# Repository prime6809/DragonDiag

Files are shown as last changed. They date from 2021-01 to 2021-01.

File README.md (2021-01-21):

# DragonDiag
Diagnotic card for the Dragon 32/64 and Tandy CoCo 1,2,3.

Included is the Hardware design files created in Eagle, these should be 
compatible with any version of Eagale 6.x or later. Recent versions of 
KiCad should also be able to successfully import them.
Folder: hardware

The Verilog source for the onboard XC95144XL CPLD. This can be built with
Xilinx WebPack 14.7.
Folder: cpld

The 6809 source to the diagnostic ROM generally programed into the first 
8K of the onboard flash rom. To assemble this you will need lwasm available
from http://www.lwtools.ca/ You will also need a nnix compatible make utility
I generally use cygwin, but it should be builable under Linux / Macos or 
any unix like environment with the correct tools.
Folder: src

The stl files for a case for both the diag board and the LCD display are
also provided along the the FreeCAD source files.
Folder: case

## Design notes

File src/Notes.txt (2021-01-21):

Notes for the Dragon/CoCo Diag cart.

V1.30 2020-05-27, Phill Harvey-Smith.

The Diag cart will perform the following tests on a Dragon 32, Dragon 64, Tandy
CoCo 1 or Tandy CoCo 2. It has as yet not been tested with a CoCo 3. 

The following tests will be performed in order :
Tests marked ** are *NOT* carried out on the CoCo3, as they are not relevant to
that machine 

1) 	Onboard SRAM test (SRAM on the card).  A failure at this point will
	prevent further testing, this will be indicated by the 8 LEDS on the
	bargraph coming on....this should never happen :)
	
2) 	PIAs and SAM initialized acording to DIP switches and motherboard jumpers.
	On the CoCo3 the GIME registers are also setup as needed.
	
3) 	Video ram at $0400-$0600 tested. If working output will be to screen as 
	well as LCD.
	The configured machine and detected RAM chip type will be displayed.

4) 	A quick memory test of the bottom 2 memory areas will be done. The size
	of the memory areas will be determined from the memory type selection
	jumpers on the Dragon or CoCo motherboard. They are :-

	CoCo with 4K RAMS		Dragon/CoCo with 16K or 64K RAMS
	block 0	$0000-$0FFF		$0000-$3FFF
	block 1 $1000-$1FFF  	$4000-$7FFF

	If A RAM failure occurs, then the test is eneded, and the address that 
	the failure occured at plus the data byte read and written are displayed.
	Further testing then halts until the 'next' button is pressed, this will
	end further testing of this bank.
	Pressing S3 allows the test to continue at the location following the
	location with error.

5) 	A RAM address line test, carried out in two halves testing first the 
	bottom 8 address lines then the top 8. This should help to detect address
	line faults between the CPU and SAM/GIME.

6) 	The two onboard ROM blocks $8000-$9FFF and $A000-$BFFF are checksumed. The
	checksums are displayed on the LCD and screen. In addition if the ROM has a
	recognized checksum, then it's idenetity is also displayed on the VDG screen.
	See ROM checksum table further down for expected values.
	
7) 	The PIA registers for the standard 2 PIAs at $FF00 and $FF20 are then dumped.
	Their expected contents in the Control and DDR registers of each port are checked,
	and the status displayed OK/NO on the VDG or Y/N on the LCD.
	
8) 	The number of spurious NMI and FIRQ interrupts are displayed. (there should 
	be none).

9) 	The above interrupts are then tested by being triggered via the onboard CPLD,
	and the results displayed.

	The IRQ interrupt is also enabled, from the VDG, if working LED X1 will begin 
	flashing approximately once per second.
   
10) The CART / CTS and P2 / SCS signals will then be tested by triggering them 
	using the CPLD, and the status displayed, either pass if they trigger as 
	expected, fail if they do not, or "stuck low" if they are low when not 
	being triggered.
	
11) ** If the DIP switch is set for long tests, then a more exhaustive long memory test
	is performed. As with the quick test it will stop on failure and wait for the 
	'next' button to be pressed.
	
12) **	If the appropreate DIP switches are set the Dragon 64 tests are done. These 
    	are:
		a) Checksumming the ROM that is copied into upper RAM when booted into 
		   RAM mode. 	
		b) Dumping the ACIA registers.

13) ** 	If the machine is detected as having 64K DRAMS, then the upper half of the 
	64K of RAM is tested. If the long test DIP is set, then the long test is ran 
	otherwise the short test.
	
14) **	The Dragon Plus addon is probed for, if found it's RAM is also tested.	

15) 	If the machine is a CoCo 3, the following additional tests are done :

		a) The additional ROMS at $C000-$FDFF are read and checksummed, 
		   and results displayed on screen / LCD.
	
		b) The ammount of RAM 128K or 512K is probed for, sequentially
		   paged in (8K at a time) and tested, whilst testing it's block
		   number is displayed plus the normal PASSED or error report.
		   
16) 	At this point all tests are complete, a message will be displayed and the
    	user has the option of pressing 'next' to enter toggle mode. 
	
Toggle mode.

As an aid to fault tracing, toggle mode is entered once all tests are complete
this mode will repeatedly read the addresses of different parts of the system so
that the correct operaion of the chip select lines can be verified.

The things toggled are :

device		Base	74LS138 pin	In addition
RAM read 	$0000	Y0 pin 15	/RAS on bank 0 of RAMS
RAM read 	$1000	Y0 pin 15	/RAS on bank 1 of RAMS (4K) **	
RAM read 	$4000	Y0 pin 15	/RAS on bank 1 of RAMS (16K) **
ROM0 		$8000	Y1 pin 14	
ROM1		$A000	Y2 pin 13
ROM2 (cart)	$C000	Y3 pin 12
PIA0		$FF00	Y4 pin 11
PIA1		$FF20	Y5 pin 10
I/O 2 (cart)	$FF40	Y6 pin 9
RAM write 	$0000	Y7 pin 7	/RAS and /WE on bank 0 of RAMS
RAM write	$1000	Y7 pin 7	/RAS and /WE on bank 1 of RAMS (4K) **	
RAM write	$4000	Y7 pin 7	/RAS and /WE on bank 1 of RAMS (16K) **

** On machines with 64K RAMs there is only one RAS signal so RAS0 will toggle 
not RAS1.
 	
Whilst in toggle mode the following keys are available

	Next will exit the toggle mode and restart the diag cart.
	S3 will move to the next toggle in the list, looping at the end.
	S4 will move to the previous toggle in the list, looping at the beginning.

User interface buttons :
There are currently 4 buttons on the card, of which 3 are currently used

	Label			Purpose
	S1 / Next		Moves to the next test, after an error occurs.
	S2 / Pause		Will pause further testing until pause is 
				pressed again.
				A LED will light to indicate the paused state.
	S3			Unused
	S4			If pressed whilst initial signon message is 
				displayed then the software build date will be
				displayed on the LCD before commencing the tests.
	
	Boot			Hold down when pressing Reset, to boot into 
				normal Basic mode, there is also a jumper for 
				this.

Jumpers
	Boot			As with Boot button above, used to set it 
				without having to  press at each power on 
				/ reset.
	AS			Autostart, if jumpered the ROM will be 
				autostarted like a standard Dragon cartridge. 
				This is usefull if other ROMS are present in 
				the ROM banks of the cartridge.
					
The function of the DIP switches (beneath LED array) is as follows :

	DIP 4			Machine is Dragon (right/on) or CoCo (left/off)
	DIP 3			Set RAM type directly from DIP1, DIP2 (on)
				Set machine type from DIP1, DIP2 (off)
	DIP 2			Machine model / RAM chip type msb
	DIP 1			Machine model / RAM chip type lsb

Note the silkscreen on the Mk 1.2 boards incorrectly labels the Dragon/CoCo switch
this has been fixed on the Mk 1.4 boards.
	
If Machine is set as Dragon then DIP 1/2 are as follows

	Model			DIP 2		DIP 1
	Dragon 32		off		off
	Dragon 64		off		on
	Dragon Alpha		on		on

If machine is set to CoCo then the machine switches are as follows :
	Model			DIP 2		DIP 1
	CoCo 1/2		off		off
	CoCo3			off		on

If DIP 3 is set on, then the RAM chip type will be set directly from the 
settings of DIP 1 and DIP 2. This is to allow a machine's RAM to be tested 
correctly if the RAM type detect fails (for example because of a faulty PIA, or
incorrect jumper setting)

	Chip type		DIP 2		DIP 1
	4K			off		off
	16K			off		on
	64K			on		off
	Static			on		on

The control DIP switches have the following functions :

	DIP 4	When on tests will repeat in sequence forever, only stopping on
		a ram error.
	DIP 3	No delays between tests, usefull to run through all tests 
		without delays between, only really usefull if VDG display is
		working.
	DIP 2	Skip long tests if on.
	DIP 1	If the machine has 4K or 16K RAMS only test 1 bank. This stops
		the test generating an error when testing a non existant bank 
		(on a CoCo).

Note if DIP2 Skip long tests is on, then the following RAM tests are still
carried out but using the quick test routine rather than the exhaustive RAM 
test : 

Upper 32K, Dragon Plus, CoCo 3 RAM block test.

Indicator LEDS and their meaning.

	LED		Meaning
	12V		12V is present on the cartridge connector. Should be 
			lit for the CoCo 1, and Dragon 32/64. Will not be lit
			on CoCo 2/3.
	5V		5V is present on the cartridge connector. Should be lit
			on all machines.
	-12V		-12V is present on the cartridge connector. Will only 
			be lit on CoCo 1.

	E		Lit if the E clock is present and running.
	Q		Lit if the Q clock is present and running.
			
	HALT		Lit if the HALT line is LOW, if lit the HALT line may
			be shorted to ground.
	Reset		Lit if the Reset line is LOW, if lit the Reset line may
			be shorted to ground. Should light if RESET button on 
			Dragon/CoCo is pressed.

Machine 		Voltage LEDS that should be lit.
Dragon 32/64/Alpha	+12V and +5V
CoCo 1			+12V, +5V -12V
CoCo 2/3		+5V

E and Q should always be lit for all machines, if either is not lit it may
indicate a SAM failure, or one of the clock lines is shorted to ground.

Reset and HALT should be off during normal running, Reset will light when the
reset button on the machine is pressed but should go out once released. Note
on the Dragon 64, HALT will also light when reset is pressed, this is normal
and is due to a diode that pulls HALT low when reset is active. 

Things the board will not test / relies on being working.

1) The 6809 CPU must be on and working. 
2) The 74LS783 / 74LS785 SAM / GIME must be woring and generating clocks.
3) There must be no shorts on the address or data busses. 
4) The board cannot detect problems with the VDG output.

However the board has been tested and woring in a Dragon 32, with the following
all removed : RAM, ROMS, both PIAs, and VDG.			

The board currently performs no interactive tests such as keyboard / joysticks /
cassette / sound etc, as these generally will not stop the machine booting and
can be tested using already existing software (e.g. the DragonData Diag cart).

Memory / I/O map.

Note all Memory and I/O is decoded directly from the address lines and bus
signals CTS/Cart and SCS/P2 are *NOT* used except for accesses to the locations
detailed below, under Triggers. This is needed so that we can assert SLENB / 
DSD to override the internal decoding, and so that we can control when these
lines are triggered to test their correct operation.

$C000-$DFFF	Onboard ROM
$E000-$FEFF	Onboard static RAM
$FF40-$FF09	I/O, see below
$FFF0-$FFFF	Onboard ROM**

** The vectors are read from the onboard ROM, and the DSD/SLENB line is 
activated to override the ROM mapping on the motherboard, so that we boot 
direct to our ROM as booting through the onboard ROM relies on too much of the
hardware being working to make an effective diag board. Holding down the 'Boot'
button whilst pressing reset will disable this for this boot.

I/O map.

$FF40		LEDS 0..7
$FF41		LEDS X1,X2

$FF42		Dip switches :-
	%00000001	LSB of machine type / RAM type
	%00000010	MSB of machine type / RAM type
	%00000100	Machine or Ram type
	%00001000	Dragon or CoCo
	%00010000	Only test one bank
	%00100000	Skip long tests
	%01000000	No delay between tests
	%10000000	Test continually, loop to beginning once all tests
			complete

$FF43		Buttons
	%00000001	Next
	%00000010	Pause
	%00000100	S2
	%00001000	S3

$FF44		Status register
	%00000001	Live CTS / CSEL (R)
	%00000010	Live P2 / SCS (R)
	%00000100	CTS access was latched (R)
	%00001000	P2 access was latched (R)
	%00010000	Disable mapping of diag board ROM and RAM when 1 (R/W)
	%00100000	FIRQ trigger is counting (R), Start FIRQ counter W=1
	%01000000	NMI trigger is counting (R), Start NMI counter W=1
	%10000000	Status ready flag (R/W)

$FF45		Reset CTS/P2 latches, by writing (any value) to here.

$FF48		LCD Command register
$FF49		LCD Data register

Triggers :

$DEFF		Trigger a CTS/CART access, latched in status reg.
$FF50		Trigger a SCS/P2 access, latched in status reg.

ROM bank selection DIP.
As supplied, Switch 1 on the bank selection DIP is not used, and 1 of 4 banks
may be selected with switches 2 and 3, the next version will allow for switch
4 to be used also to select 1 of 8.

DIP 2	DIP 3		ROM
up	up		Ramoth Diag ROM, drives hardware on card overrides 
			internal ROM
down	up		Dragon Data diag ROM, compiled for Dragon.
up	down		Dragon Data diag ROM, compiled for CoCo.
down	down		Currently unused.

Note the Dragon Data Diag roms, also required the fitting of the AS and Boot
jumpers to boot the machin into 'normal' mode. It is intended they are used
for further interactive testing once the main diag ROM has passed the machine
without faults.

ROM Checksum table

Displayed	Displayed  		Machine
Checksum	ROM ID (VDG)	
$B44F		D32 LO			Dragon 32 low rom
$DACC		D32 HI			Dragon 32 high rom	
$D753		D64 LO			Dragon 64 low rom (ROM mode)
$1968		D64 HI			Dragon 64 high rom (ROM mode)	

$7A31		D64-LO			Dragon 64 low rom (RAM mode)
$ABE9		D64-LO			Dragon 64 high rom (RAM mode)

$E619		cb1.2d			DraCo, CoCo colour basic 1.2 modified 
					for Dragon hardware
		
$677C		CB 1.0			CoCo Color basic 1.0
$8DC2		CB 1.1			CoCo Color basic 1.1
$1313		CB 1.2			CoCo Color basic 1.2
$9E9F		CB 1.2			CoCo Color basic 1.2, CoCo3
$AD56		CB 1.3			CoCo Color basic 1.3

$E321		cb 1.1			LZ Colour 64, CB 1.1 (clone/pirate).
$96BF		cb ???			MX-1600, CB unknown,(clone/pirate).
$5732		cb ???			CP400, CB ??? (clone/pirate).

$9E87		ECB1.0			CoCo Extended color basic 1.0 (C) 1980,
					from CoCo1
$AF87		ECB1.0			CoCo Extended color basic 1.0 (C) 1981, 
					from MESS
$40AC		ECB1.1			CoCo Extended color basic 1.1
$7F63		ECB2.0			CoCo Extended color basic 2.0, CoCo3

$F88D		ecb1.0			LZ Colour 64, ECB 1.0 (clone/pirate).
$986B		ecb1.1			MX-1600, ECB 1.1,(clone/pirate).
$7733		ecb???			CP400, ECB ??? (clone/pirate).
		
$541A		CC3-PR			CoCo3 $C000-$DFFF 'patch' rom
$C0E6		SECB 1			CoCo3 Super Extended Colour basic				
		
$FFFF		NO ROM
$0000		UNKOWN			displayed if no checksum matches

Updating the Diag ROM using a DragonMMC board.

This is the procedure to update the Flash ROM on the DIAG board via the ROM 
socket on the DragonMMC board.

Before you begin, it is **STRONGLY** suggested that you mark the DragonMMC
and DIAG ROMS so that you can tell them apart as they both use the same flash
IC.

You should also be familliar with removing and inserting ICs specifically 
how to identify pin 1 and insert the roms into the socket with the correct
orientation.

The DragonMMC also requires it's AVR firmware to be later than April 2020.

Steps :

Prepare an SD card with DIAGDGN.ROM and DIAGFSH.DGN on it.

Remove the Diag rom from the diag board and put it in the flash socket on 
the DragonMMC (first removing the DragonMMC ROM!).

Plug the DragonMMC board into the dragon and turn the dragon on. Note you will
not get the normal DragonMMC signon message, just the standard Basic sign on, 
this is normal.

Enter the following commands at the keyboard :

	POKE &HFF55,1
	POKE &HFF50,&H5E:CLOADM
	EXEC

If all is well, the diag ROM will now be flashed. Please note the second line 
**MUST** be typed as a multi statement line, or the CLOADM may fail.

Once the ROM is flashed power the dragon down, and move the diag ROM back to
the DIAG board.

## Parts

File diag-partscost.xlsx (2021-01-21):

Prices correct as of 2020-04
Component | Type | Qty | Supplier | Cat no | Cost (pounds) | Multiplier | Total | Total+VAT
IC1 | 39SF010 | 1 | Mouser | 804-39SF010A7CPHE | 0.92 | 1 | 0.92 | 1.10
IC2 | 32KSRAM-DIL600 | 1 | Mouser | 913-AS6C62256-55PCN | 1.97 | 1 | 1.97 | 2.36
IC3 | XC95144XL-TQ100 | 1 | Digikey |  | 6.56 | 1 | 6.56 | 7.87
REG1 | LEXXCZ | 1 | Rapid | 82-3010 | 0.541 | 1 | 0.54 | 0.65
D1 | 1N4148 | 1 | Rapid | 51-0100 | 0.0068 | 1 | 0.01 | 0.01
+12, HALT, E | 3mm LED red | 3 |  | 55-102 | 0.063 | 3 | 0.19 | 0.23
+5, Reset, Q | 3mm LED green | 3 |  | 55-0106 | 0.061 | 3 | 0.18 | 0.22
-12 | 3mm LED yellow | 1 |  | 55-0110 | 0.054 | 1 | 0.05 | 0.06
LED Bargraph | 10 led bargraph | 1 | Rapid | 55-0197 | 1.73 | 1 | 1.73 | 2.08
LCD1 | 2 row by 24 character | 1 | Rapid | 60-9692 | 7.87 | 1 | 7.87 | 9.44
R2, R4, R5, R6, R7, R10, R11 | 220R | 7 | Rapid | 62-3434 | 0.0168 | 2 | 0.03 | 0.04
R8, R9 | 1K | 2 | Rapid | 62-3450 | 0.0168 | 1 | 0.02 | 0.02
R3, R12, R13 | 10K | 3 | Rapid | 62-3474 | 0.0168 | 2 | 0.03 | 0.04
RN1, RN2, RN3, RN5 | 10K | 4 | Rapid | 63-0265 | 0.106 | 4 | 0.42 | 0.51
RN4 | 220R | 1 | Rapid | 63-0335 | 0.117 | 1 | 0.12 | 0.14
VR1 | 10K | 1 | Rapid | 51-6426 | 0.207 | 1 | 0.21 | 0.25
C1, C2, C4, C5, C6, C7 | 100nf | 6 | Rapid | 11-3442 | 0.064 | 15 | 0.96 | 1.15
C3 | 10uf | 2 | Rapid | 11-1220 | 0.034 | 2 | 0.07 | 0.08
AS, Boot | PINHD-1X2 | 2 | Rapid | 22-0545 | 0.008722222222 | 2 | 0.02 | 0.02
JTAG connector | PINHD-2X3 | 1 | Rapid | 22-0595 | 0.01838888889 | 1 | 0.02 | 0.02
LCD connector board end | 16 pin box header | 1 | Rapid | 19-0035 | 0.228 | 1 | 0.23 | 0.27
LCD connector LCD end | 16 pin box header RA | 1 | Rapid | 19-0043 | 0.247 | 1 | 0.25 | 0.30
LCD connector cable | 16 pin IDC connector | 2 | Rapid | 19-1019 | 0.165 | 2 | 0.33 | 0.40
IC1 | DIL-32-6 | 1 | Rapid | 22-1766 | 0.5486666667 | 1 | 0.55 | 0.66
IC2 | DIL-28-6 | 1 | Rapid | 22-1765 | 0.4841176471 | 1 | 0.48 | 0.58
DS1, DS2, DS3 | 4 position DIP switches | 3 | Rapid | 80-0334 | 0.37 | 3 | 1.11 | 1.33
S1,S2,S3,S4, boot | 6x6x5 mm tactile switches | 5 | Rapid | 78-0621 | 0.121 | 5 | 0.60 | 0.73
PCB @ all-pcb.com |  |  |  |  |  |  | 4.4775 | 5.37
Total Cost |  |  |  |  |  |  | 29.03 | 34.84

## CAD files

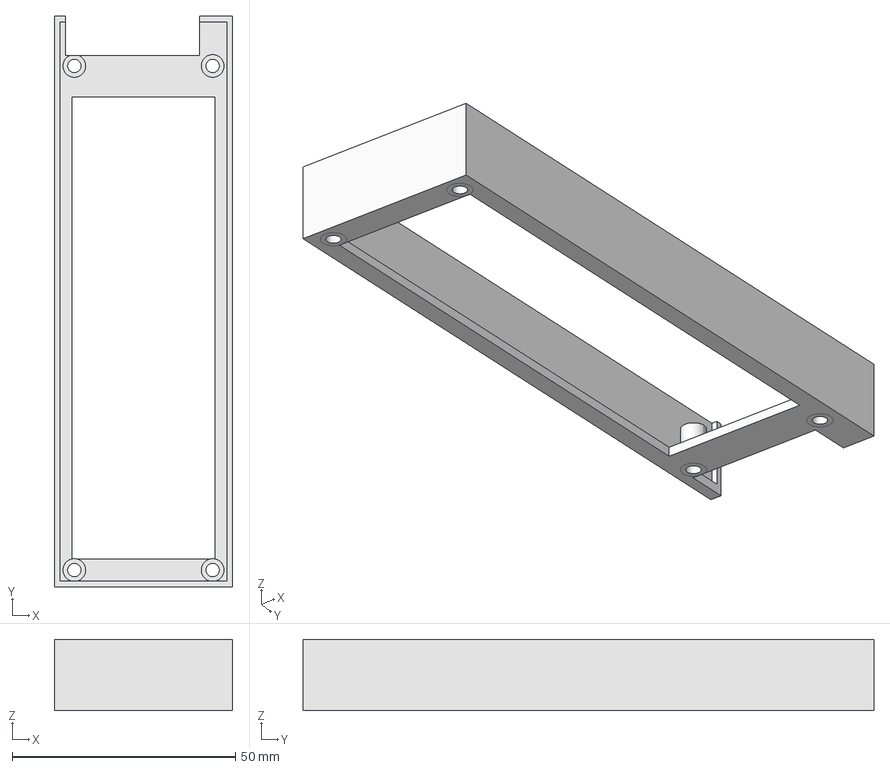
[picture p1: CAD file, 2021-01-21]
case/LCD case-v3.FCStd
40.0 x 128.0 x 16.0 mm

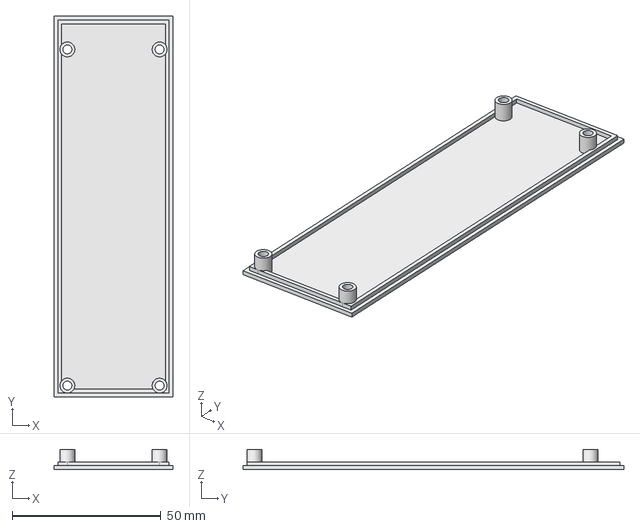
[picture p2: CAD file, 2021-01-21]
case/LCD back-no-supports-v2.FCStd
40.0 x 128.0 x 6.80 mm

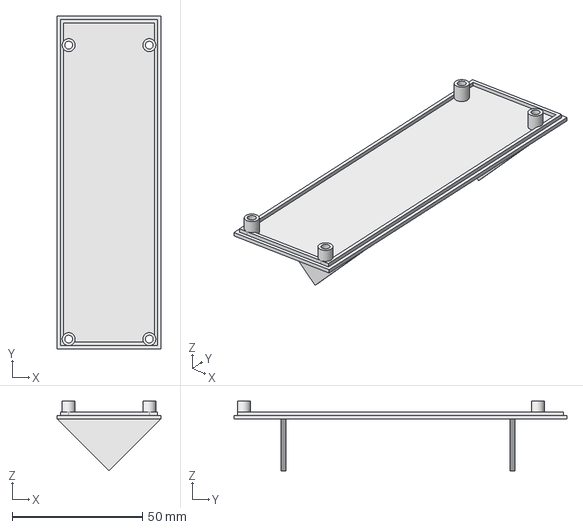
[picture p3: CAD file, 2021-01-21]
case/LCD back-v2.FCStd
40.0 x 128.0 x 26.8 mm

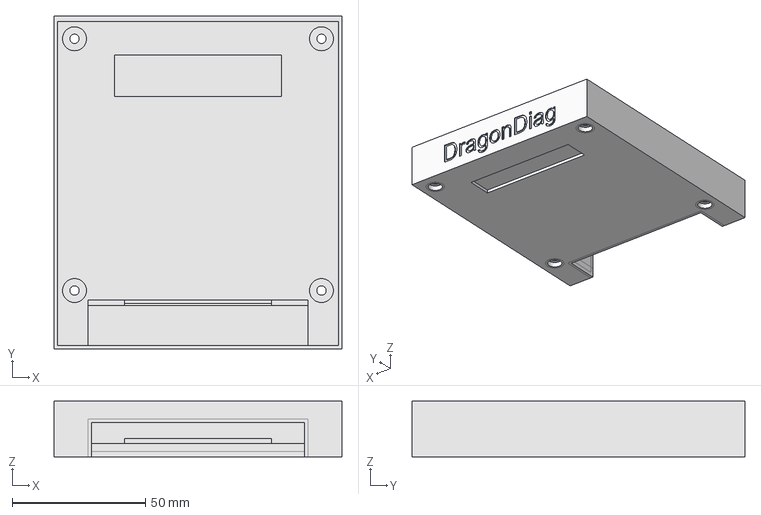
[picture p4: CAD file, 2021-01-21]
case/DragonDiagBottom-v3.FCStd
108.0 x 125.0 x 21.0 mm

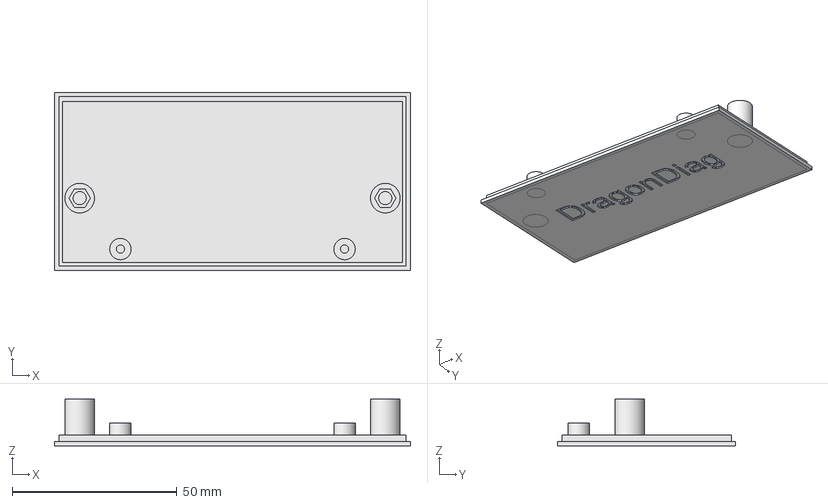
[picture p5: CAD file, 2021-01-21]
case/DragonDiagTop-v2.FCStd
108.0 x 54.0 x 14.2 mm

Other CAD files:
case/DragonDiagBottom-v3.stl
case/DragonDiagTop-v2.stl
case/LCD back-no-supports-v2.stl
case/LCD-back-v2.stl
case/LCD-case-v3.stl

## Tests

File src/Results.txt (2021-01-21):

Interpreting the results.

This is an aid to faults with the Dragon / CoCo that *MAY* cause the tests to 
fail, and will serve as an indication as to what might be the cause of the 
fault.

Test 1 / pre-test 1 fail.

If the card displays the signon message on the LCD and then turns on all 8
status LEDS this indicates a failure of the Diag card's self test. (Uusally
the onboard RAM). If possible test the card in another machine to see if this
is the case.

If the card does not sign on the LCD this may indicate a failed CPU or SAM 
chip. The LEDs should be checked and the following may be indicated :

LED 	State	Possible fault
+5V	off	Power supply fault, sometimes worth wiggling power switch.
+12V	off	On a machine with 4K/16K RAMS, may prevent RAM from working.
halt	on	HALT line to the CPU stuck low, preventing the CPU running.
reset	on	RESET line stuck low.
E	off	No E clock to CPU.
Q	off	No Q clock to CPU.

If the E and Q leds are off but you are getting a picture on the screen, this
may indicate a break of the line somewhere between the SAM and the CPU. 

Halt or Reset lines being stuck low, may indicate a short of those lines to 
ground, or that the pullup resistor on those lines has failed.

Test 2 - machine setup and initialization of SAM/PIAs.

No failures tested as this is a setup stage.

Test 3 - Video RAM test.

A Display RAM failure will be indicated on the LCD display, and will be 
something like :-
"Failed at:$0400 w$00 r$08"

This means that the ram failed at address $0400, and that the value written
was $00, but read back was $08. From this we can determine that the fault 
lies with bit 3 of the RAM. Note for display RAM tests on a non CoCo 3, this
will always be in bank 0 of a machine with 4K or 16K rams.

A failure of the 74LS244, buffer chip that is between the CPU and RAM can
also cause this fault.

Test 4 - Quick RAM test.

Prease refer to notes for Test 3 Video RAM test. However it should be noted 
that for a machine with only one bank of RAM e.g. a 4K or 16K CoCo 1/2, if
the "single bank" dip switch is not set, this test will fail on trying to 
test the non-existant second bank of RAM.

Test 5 - RAM address test.

This test is carried out in 2 parts, first a single 256 byte page of RAM is 
filled with an ascending value, and then the values are read back. A failure 
can be caused by a broken address line between A0 and A7. 

The second part fills the entire 32K with an ascending value, incremented on
each page boundry, so the first page gets $00 written to it, the next page 
$10 and so on.

This will cause a later value to over-write an earlier one. By examining 
the values you can determine which address line is broken.

e.g. if A7 where broken, then it would fail at address $00, with the value 
$80 written. 

This test will generally fail at address $00, and the value written, ill tell
you which address line is possibly faulty. 

Value	Address line	Address line
	0..7		8..F
$80	A7		A15 (not tested!)
$40	A6		A14
$20	A5		A13
$10	A4		A12
$08	A3		A11
$04	A2		A10
$02	A1		A9
$01	A0		A8

Test 6 - ROM test.

If the ROMS are recognized their checksums and identities are displayed note
that having NONE or Unknown in the $8000-$9FFF area of a CoCo 1/2 may not 
indicate a failure, if the machine does not have Extended Colour Basic fitted.

In other cases check that the roms identified match what you would expect for
that machine. Note also that a DraCo machine in CoCo mode will find CB/ECB 
but find Dragon roms in Dragon mode.

Test 7 - PIA test.

A failure at this point may indicate a bad PIA, or possibly an address decoding
error (usually a failure of the 74LS138), the toggle test may be able to help
you determine this.

Test 8 - spurious interrupt test.

If any spurious FIRQ or NMI interrupts are displayed then this may indicate a 
short to one of the interrupt lines, or possibly a failure in the line's pullup
resistor.

Test 9 - Interrrupt test.

A failure in the NMI test may indicate a faulty NMI line on the CPU, or a break / 
short in the NMI line somewhere between the cartridge port and the CPU.

A failure in the FIRQ test may indicate a faulty FIRQ line on the CPU, it may 
also indicate a fault with PIA1, or with the lines between the cartridge port and
PIA1, or between PIA1 and the CPU.

The X1 LED should begin to flash at approximately 1Hz, if it does then the IRQ is
working. Failing to flash may indicate a faulty IRQ line on the CPU, it may 
also indicate a fault with PIA0, or with the lines between the 6847 VDG and
PIA0, or between PIA0 and the CPU.

Test 10 - Cartridge select signals.

A failure to trigger of CART / CTS or P2 /SCS may indicate a broken line between
the 74LS138 address decoder and the cartridge port, or that the lines is shorted
to ground or to +5V.

Test 11 - Long RAM test.

For details see test 3 and test 4.

Test 12 - Dragon 64 tests.

Check for expected ROM checksums for second ROM.
More extensive ACIA tests to follow, currently just dumps registers.

Test 13 - Upper RAM test.

For details see test 3 and test 4.

Test 14 - Dragon Plus test.

For details see test 3 and test 4, however a fail here may indicate a faulty RAM
on the Dragon plus board. Check that correct message is displayed on Dragon Plus
screen.

Test 15 - CoCo 3 tests.

Check for correct checksums for $C000-$DFFF and $E000-$FE00 ROMS.
RAM failure meaning will generally indicate which chip has failed, for a 128K 
CoCo 3 this will be one of the 64Kx4 RAMs on the mainboard, for expanded machines
this will indicate a chip on your expansion board.

General.

If the board boots but all tests seem to fail, or give unknown / bad results in the
case of the ROM and PIA tests, check the status of the DSD / SLENB line (pin 6 on 
the 74LS138) With no cartridge in the machine measure the voltage level on this line 
with the machine on, it should be close to 5.0V. This line is generally pulled up via 
a 4.7K resistor, so with the machine off the resistance between pins 6 an 16 of the 
74LS138 should be arrounf 4.7K.

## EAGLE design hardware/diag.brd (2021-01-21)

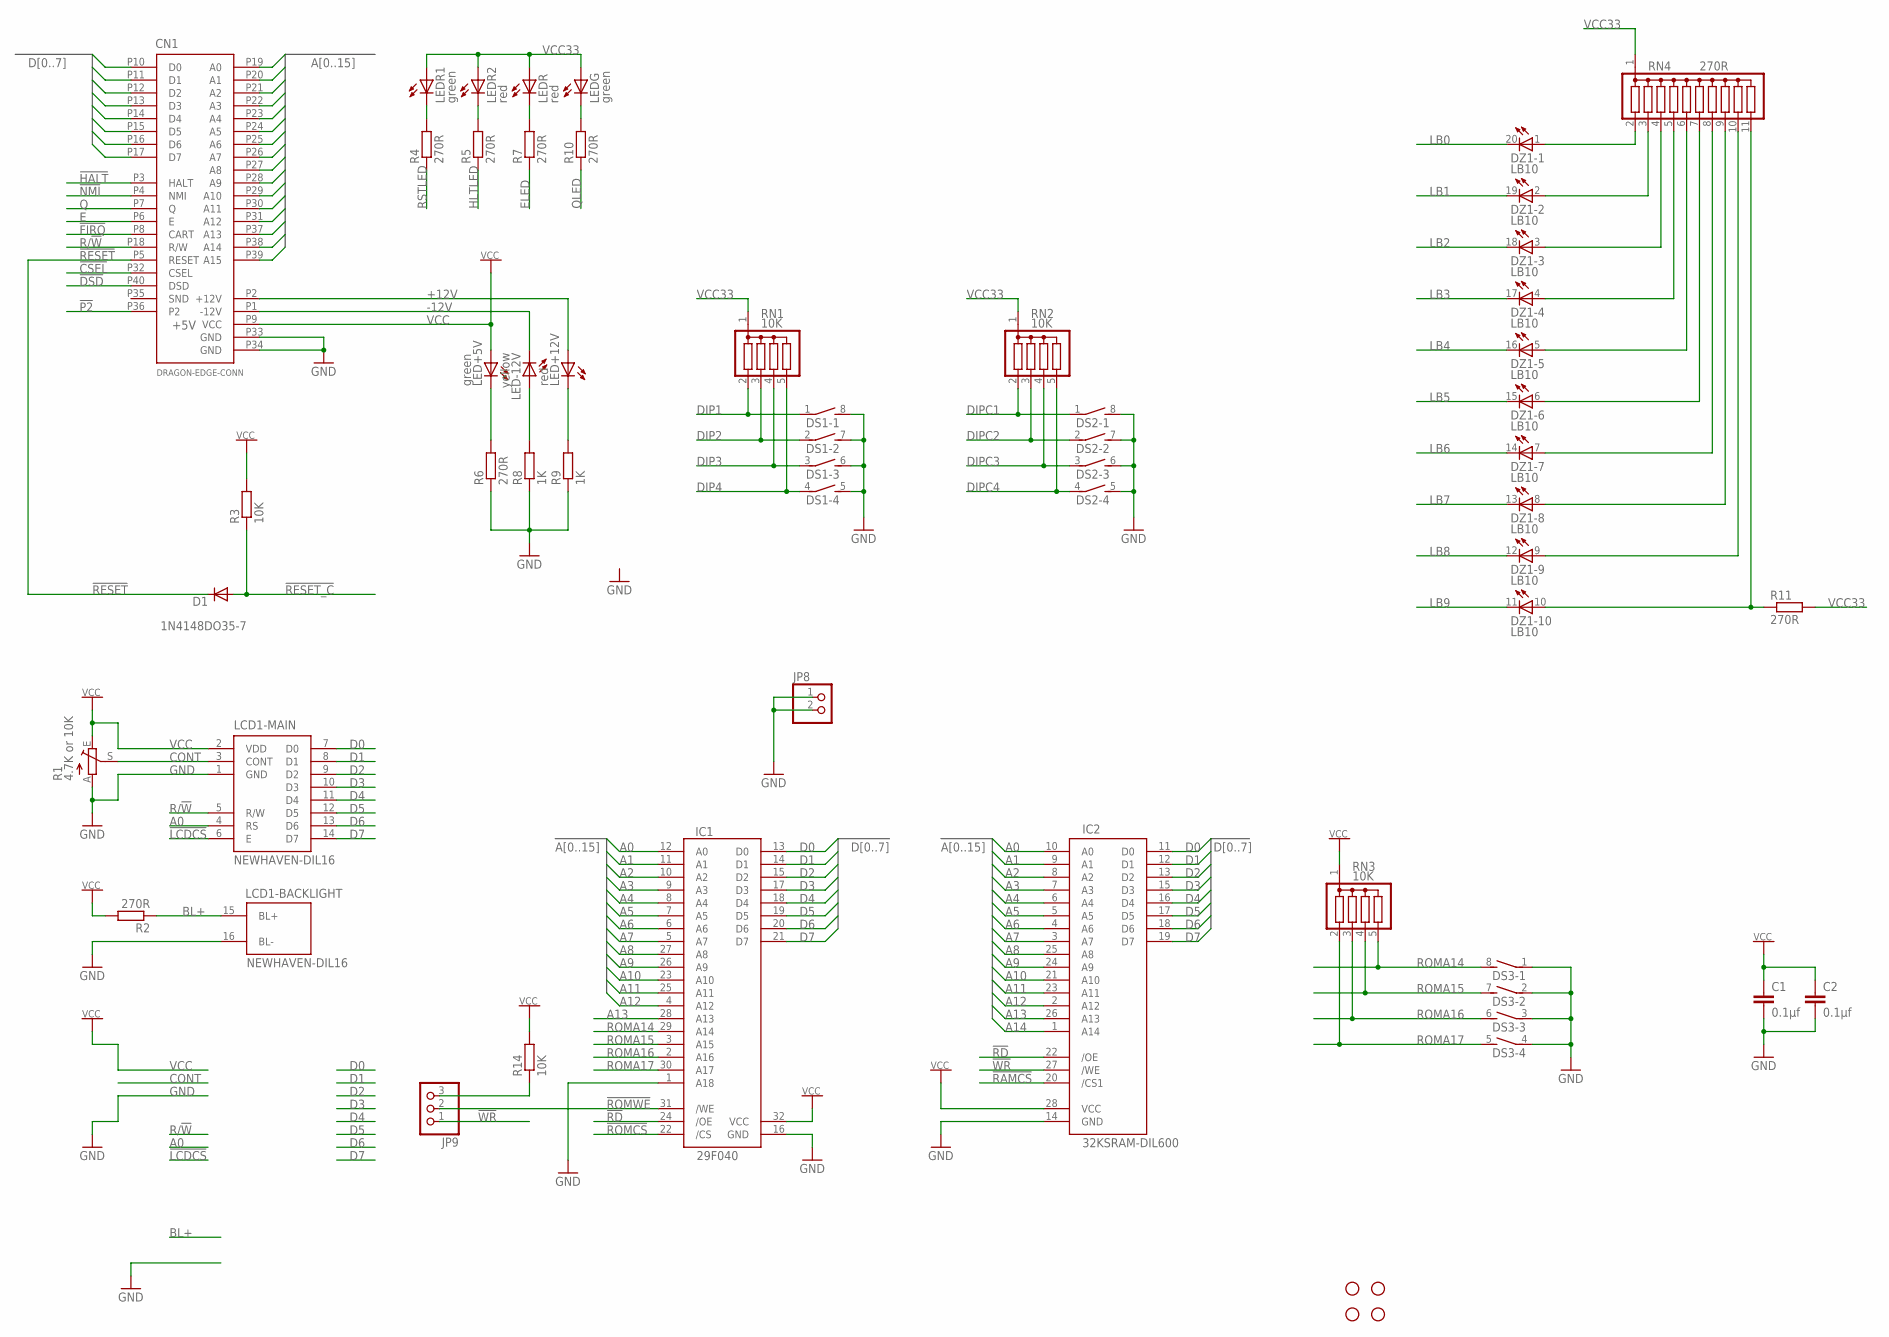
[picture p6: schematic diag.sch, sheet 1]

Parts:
C1, C2: 0.1µf; C025-025X050
CN1: DRAGON-EDGE-CONN; EDGE-40-01
D1: 1N4148DO35-7; DO35-7
DS1, DS2, DS3: DIP04S
DZ1: LB10
IC1: 29F040; DIL32
IC2: 32KSRAM-DIL600; DIL28-6
JP1, JP2, JP3, JP4: STAND-OFF
JP8: PINHD-1X2; 1X02
JP9: PINHD-1X3; 1X03
LCD1: NEWHAVEN-DIL16; 2X08
LED+5V: green; LED3MM
LED+12V: red; LED3MM
LED-12V: yellow; LED3MM
LEDG: green; LED3MM
LEDR, LEDR2: red; LED3MM
LEDR1: green; LED3MM
R1: 4.7K or 10K; CA9V
R2, R4, R5, R6, R7, R10, R11: 270R; 0207/10
R3: 10K; 0204/7
R8, R9: 1K; 0207/10
R14: 10K; 0207/10
RN1, RN2, RN3: 10K; SIL5
RN4: 270R; SIL11

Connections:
!CSEL: CN1.P32 (CSEL); also elsewhere on the board
!DSD: CN1.P40 (DSD); also elsewhere on the board
!FIRQ: CN1.P8 (CART); also elsewhere on the board
!HALT: CN1.P3 (HALT); also elsewhere on the board
!LCDCS: LCD1.6 (E); also elsewhere on the board
!NMI: CN1.P4 (NMI); also elsewhere on the board
!P2: CN1.P36 (P2); also elsewhere on the board
!RAMCS: IC2.20 (/CS1); also elsewhere on the board
!RD: IC1.24 (/OE), IC2.22 (/OE); also elsewhere on the board
!RESET: CN1.P5 (RESET), D1.C
!RESET_C: D1.A, R3.1; also elsewhere on the board
!ROMCS: IC1.22 (/CS); also elsewhere on the board
!ROMWE: IC1.31 (/WE), JP9.2
!WR: IC2.27 (/WE), JP9.1; also elsewhere on the board
+12V: CN1.P2 (+12V), LED+12V.A
-12V: CN1.P1 (-12V), LED-12V.K (C)
A0: CN1.P19 (A0), IC1.12 (A0), IC2.10 (A0), LCD1.4 (RS); also elsewhere on the board
A1: CN1.P20 (A1), IC1.11 (A1), IC2.9 (A1); also elsewhere on the board
A2: CN1.P21 (A2), IC1.10 (A2), IC2.8 (A2); also elsewhere on the board
A3: CN1.P22 (A3), IC1.9 (A3), IC2.7 (A3); also elsewhere on the board
A4: CN1.P23 (A4), IC1.8 (A4), IC2.6 (A4); also elsewhere on the board
A5: CN1.P24 (A5), IC1.7 (A5), IC2.5 (A5); also elsewhere on the board
A6: CN1.P25 (A6), IC1.6 (A6), IC2.4 (A6); also elsewhere on the board
A7: CN1.P26 (A7), IC1.5 (A7), IC2.3 (A7); also elsewhere on the board
A8: CN1.P27 (A8), IC1.27 (A8), IC2.25 (A8); also elsewhere on the board
A9: CN1.P28 (A9), IC1.26 (A9), IC2.24 (A9); also elsewhere on the board
A10: CN1.P29 (A10), IC1.23 (A10), IC2.21 (A10); also elsewhere on the board
A11: CN1.P30 (A11), IC1.25 (A11), IC2.23 (A11); also elsewhere on the board
A12: CN1.P31 (A12), IC1.4 (A12), IC2.2 (A12); also elsewhere on the board
A13: CN1.P37 (A13), IC1.28 (A13), IC2.26 (A13); also elsewhere on the board
A14: CN1.P38 (A14), IC2.1 (A14); also elsewhere on the board
A15: CN1.P39 (A15); also elsewhere on the board
BL+: LCD1.15 (BL+), R2.1
CONT: LCD1.3 (CONT), R1.S
D0: CN1.P10 (D0), IC1.13 (D0), IC2.11 (D0), LCD1.7 (D0); also elsewhere on the board
D1: CN1.P11 (D1), IC1.14 (D1), IC2.12 (D1), LCD1.8 (D1); also elsewhere on the board
D2: CN1.P12 (D2), IC1.15 (D2), IC2.13 (D2), LCD1.9 (D2); also elsewhere on the board
D3: CN1.P13 (D3), IC1.17 (D3), IC2.15 (D3), LCD1.10 (D3); also elsewhere on the board
D4: CN1.P14 (D4), IC1.18 (D4), IC2.16 (D4), LCD1.11 (D4); also elsewhere on the board
D5: CN1.P15 (D5), IC1.19 (D5), IC2.17 (D5), LCD1.12 (D5); also elsewhere on the board
D6: CN1.P16 (D6), IC1.20 (D6), IC2.18 (D6), LCD1.13 (D6); also elsewhere on the board
D7: CN1.P17 (D7), IC1.21 (D7), IC2.19 (D7), LCD1.14 (D7); also elsewhere on the board
DIP1: DS1.1, RN1.2; also elsewhere on the board
DIP2: DS1.2 (1), RN1.3; also elsewhere on the board
DIP3: DS1.3 (1), RN1.4; also elsewhere on the board
DIP4: DS1.4 (1), RN1.5; also elsewhere on the board
DIPC1: DS2.1, RN2.2; also elsewhere on the board
DIPC2: DS2.2 (1), RN2.3; also elsewhere on the board
DIPC3: DS2.3 (1), RN2.4; also elsewhere on the board
DIPC4: DS2.4 (1), RN2.5; also elsewhere on the board
E: CN1.P6 (E); also elsewhere on the board
ELED: R7.1; also elsewhere on the board
GND: C1.2, C2.2, CN1.P33 (GND), CN1.P34 (GND), DS1.5 (2), DS1.6 (2), DS1.7 (2), DS1.8 (2), DS2.5 (2), DS2.6 (2), DS2.7 (2), DS2.8 (2), DS3.1, DS3.2 (1), DS3.3 (1), DS3.4 (1), IC1.1 (A18), IC1.16 (GND), IC2.14 (GND), JP8.1, JP8.2, LCD1.1 (GND), LCD1.16 (BL-), R1.A, R6.1, R8.1, R9.1; also elsewhere on the board
HLTLED: R5.1; also elsewhere on the board
LB0: DZ1.20 (C); also elsewhere on the board
LB1: DZ1.19 (C); also elsewhere on the board
LB2: DZ1.18 (C); also elsewhere on the board
LB3: DZ1.17 (C); also elsewhere on the board
LB4: DZ1.16 (C); also elsewhere on the board
LB5: DZ1.15 (C); also elsewhere on the board
LB6: DZ1.14 (C); also elsewhere on the board
LB7: DZ1.13 (C); also elsewhere on the board
LB8: DZ1.12 (C); also elsewhere on the board
LB9: DZ1.11 (C); also elsewhere on the board
unnamed: LED+12V.K (C), R9.2
unnamed: LED+5V.K (C), R6.2
unnamed: DZ1.1 (A), RN4.2
unnamed: DZ1.2 (A), RN4.3
unnamed: LED-12V.A, R8.2
unnamed: DZ1.3 (A), RN4.4
unnamed: DZ1.4 (A), RN4.5
unnamed: DZ1.5 (A), RN4.6
unnamed: DZ1.6 (A), RN4.7
unnamed: LEDR.K (C), R7.2
unnamed: DZ1.7 (A), RN4.8
unnamed: DZ1.8 (A), RN4.9
unnamed: LEDG.K (C), R10.2
unnamed: DZ1.9 (A), RN4.10
unnamed: DZ1.10 (A), R11.1, RN4.11
unnamed: LEDR1.K (C), R4.2
unnamed: LEDR2.K (C), R5.2
unnamed: JP9.3, R14.1
Q: CN1.P7 (Q); also elsewhere on the board
QLED: R10.1; also elsewhere on the board
R/!W: CN1.P18 (R/W), LCD1.5 (R/W); also elsewhere on the board
ROMA14: DS3.8 (2), IC1.29 (A14), RN3.5
ROMA15: DS3.7 (2), IC1.3 (A15), RN3.4
ROMA16: DS3.6 (2), IC1.2 (A16), RN3.3
ROMA17: DS3.5 (2), IC1.30 (A17), RN3.2
RSTLED: R4.1; also elsewhere on the board
VCC: C1.1, C2.1, CN1.P9 (VCC), IC1.32 (VCC), IC2.28 (VCC), LCD1.2 (VDD), LED+5V.A, R1.E, R2.2, R3.2, R14.2, RN3.1; also elsewhere on the board
VCC33: LEDG.A, LEDR.A, LEDR1.A, LEDR2.A, R11.2, RN1.1, RN2.1, RN4.1; also elsewhere on the board

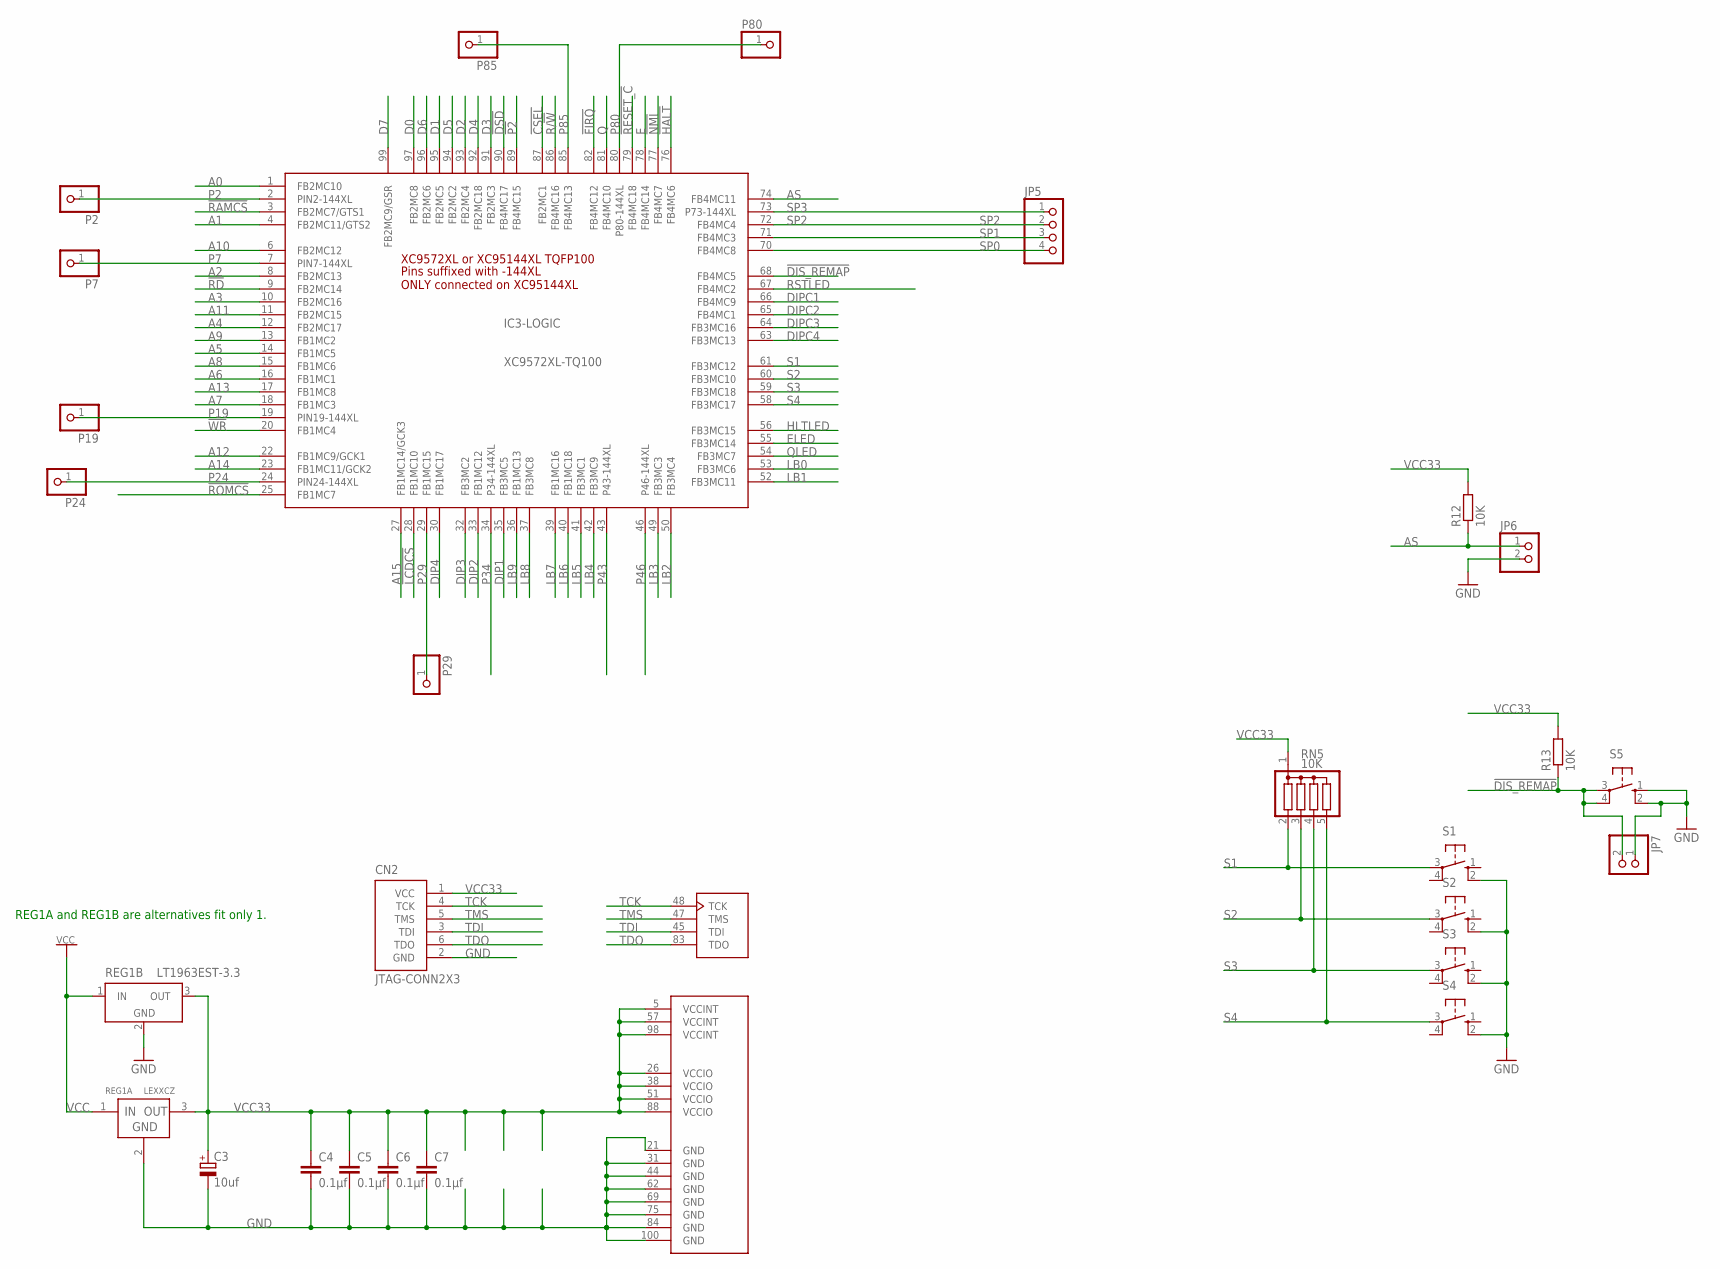
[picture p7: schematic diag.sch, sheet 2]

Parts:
C3: 10uf; TT2D7
C4, C5, C6, C7: 0.1µf; C025-025X050
CN2: JTAG-CONN2X3; 2X3
IC3: XC9572XL-TQ100; TQ100
JP5: PINHD-1X4; 1X04
JP6, JP7: PINHD-1X2; 1X02
P2, P7, P19, P24, P29, P80, P85: PINHD-1X1; 1X01
R12, R13: 10K; 0207/10
REG1A: LEXXCZ; TO92-
REG1B: LT1963EST-3.3; SOT223
RN5: 10K; SIL5
S1, S2, S3, S4, S5: 10-XX; B3F-10XX

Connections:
!CSEL: IC3.87 (FB2MC1); also elsewhere on the board
!DIS_REMAP: IC3.68 (FB4MC5), JP7.2, R13.1, S5.3, S5.4 (P1)
!DSD: IC3.90 (FB4MC17); also elsewhere on the board
!FIRQ: IC3.82 (FB4MC12); also elsewhere on the board
!HALT: IC3.76 (FB4MC6); also elsewhere on the board
!LCDCS: IC3.28 (FB1MC10); also elsewhere on the board
!NMI: IC3.77 (FB4MC7); also elsewhere on the board
!P2: IC3.89 (FB4MC15); also elsewhere on the board
!RAMCS: IC3.3 (FB2MC7/GTS1); also elsewhere on the board
!RD: IC3.9 (FB2MC14); also elsewhere on the board
!RESET_C: IC3.79 (FB4MC18); also elsewhere on the board
!ROMCS: IC3.25 (FB1MC7); also elsewhere on the board
!WR: IC3.20 (FB1MC4); also elsewhere on the board
A0: IC3.1 (FB2MC10); also elsewhere on the board
A1: IC3.4 (FB2MC11/GTS2); also elsewhere on the board
A2: IC3.8 (FB2MC13); also elsewhere on the board
A3: IC3.10 (FB2MC16); also elsewhere on the board
A4: IC3.12 (FB2MC17); also elsewhere on the board
A5: IC3.14 (FB1MC5); also elsewhere on the board
A6: IC3.16 (FB1MC1); also elsewhere on the board
A7: IC3.18 (FB1MC3); also elsewhere on the board
A8: IC3.15 (FB1MC6); also elsewhere on the board
A9: IC3.13 (FB1MC2); also elsewhere on the board
A10: IC3.6 (FB2MC12); also elsewhere on the board
A11: IC3.11 (FB2MC15); also elsewhere on the board
A12: IC3.22 (FB1MC9/GCK1); also elsewhere on the board
A13: IC3.17 (FB1MC8); also elsewhere on the board
A14: IC3.23 (FB1MC11/GCK2); also elsewhere on the board
A15: IC3.27 (FB1MC14/GCK3); also elsewhere on the board
AS: IC3.74 (FB4MC11), JP6.1, R12.1
D0: IC3.97 (FB2MC8); also elsewhere on the board
D1: IC3.95 (FB2MC5); also elsewhere on the board
D2: IC3.93 (FB2MC4); also elsewhere on the board
D3: IC3.91 (FB2MC3); also elsewhere on the board
D4: IC3.92 (FB2MC18); also elsewhere on the board
D5: IC3.94 (FB2MC2); also elsewhere on the board
D6: IC3.96 (FB2MC6); also elsewhere on the board
D7: IC3.99 (FB2MC9/GSR); also elsewhere on the board
DIP1: IC3.35 (FB3MC5); also elsewhere on the board
DIP2: IC3.33 (FB1MC12); also elsewhere on the board
DIP3: IC3.32 (FB3MC2); also elsewhere on the board
DIP4: IC3.30 (FB1MC17); also elsewhere on the board
DIPC1: IC3.66 (FB4MC9); also elsewhere on the board
DIPC2: IC3.65 (FB4MC1); also elsewhere on the board
DIPC3: IC3.64 (FB3MC16); also elsewhere on the board
DIPC4: IC3.63 (FB3MC13); also elsewhere on the board
E: IC3.78 (FB4MC14); also elsewhere on the board
ELED: IC3.55 (FB3MC14); also elsewhere on the board
GND: C3.-, C4.2, C5.2, C6.2, C7.2, CN2.2 (GND), IC3.21 (GND), IC3.31 (GND), IC3.44 (GND), IC3.62 (GND), IC3.69 (GND), IC3.75 (GND), IC3.84 (GND), IC3.100 (GND), JP6.2, JP7.1, REG1A.2 (GND), REG1B.2 (GND), REG1B.4 (GND), S1.2 (S1), S2.2 (S1), S3.2 (S1), S4.2 (S1), S5.1 (S), S5.2 (S1); also elsewhere on the board
HLTLED: IC3.56 (FB3MC15); also elsewhere on the board
LB0: IC3.53 (FB3MC6); also elsewhere on the board
LB1: IC3.52 (FB3MC11); also elsewhere on the board
LB2: IC3.50 (FB3MC4); also elsewhere on the board
LB3: IC3.49 (FB3MC3); also elsewhere on the board
LB4: IC3.42 (FB3MC9); also elsewhere on the board
LB5: IC3.41 (FB3MC1); also elsewhere on the board
LB6: IC3.40 (FB1MC18); also elsewhere on the board
LB7: IC3.39 (FB1MC16); also elsewhere on the board
LB8: IC3.37 (FB3MC8); also elsewhere on the board
LB9: IC3.36 (FB1MC13); also elsewhere on the board
P2: IC3.2 (PIN2-144XL), P2.1
P7: IC3.7 (PIN7-144XL), P7.1
P19: IC3.19 (PIN19-144XL), P19.1
P24: IC3.24 (PIN24-144XL), P24.1
P29: IC3.29 (FB1MC15), P29.1
P34: IC3.34 (P34-144XL)
P43: IC3.43 (P43-144XL)
P46: IC3.46 (P46-144XL)
P80: IC3.80 (P80-144XL), P80.1
P85: IC3.85 (FB4MC13), P85.1
Q: IC3.81 (FB4MC10); also elsewhere on the board
QLED: IC3.54 (FB3MC7); also elsewhere on the board
R/!W: IC3.86 (FB4MC16); also elsewhere on the board
RSTLED: IC3.67 (FB4MC2); also elsewhere on the board
S1: IC3.61 (FB3MC12), RN5.2, S1.3
S2: IC3.60 (FB3MC10), RN5.3, S2.3
S3: IC3.59 (FB3MC18), RN5.4, S3.3
S4: IC3.58 (FB3MC17), RN5.5, S4.3
SP0: IC3.70 (FB4MC8), JP5.4
SP1: IC3.71 (FB4MC3), JP5.3
SP2: IC3.72 (FB4MC4), JP5.2
SP3: IC3.73 (P73-144XL), JP5.1
TCK: CN2.4 (TCK), IC3.48 (TCK)
TDI: CN2.3 (TDI), IC3.45 (TDI)
TDO: CN2.6 (TDO), IC3.83 (TDO)
TMS: CN2.5 (TMS), IC3.47 (TMS)
VCC: REG1A.1 (IN), REG1B.1 (IN); also elsewhere on the board
VCC33: C3.+, C4.1, C5.1, C6.1, C7.1, CN2.1 (VCC), IC3.5 (VCCINT), IC3.26 (VCCIO), IC3.38 (VCCIO), IC3.51 (VCCIO), IC3.57 (VCCINT), IC3.88 (VCCIO), IC3.98 (VCCINT), R12.2, R13.2, REG1A.3 (OUT), REG1B.3 (OUT), RN5.1; also elsewhere on the board

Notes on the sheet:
REG1A and REG1B are alternatives fit only 1.

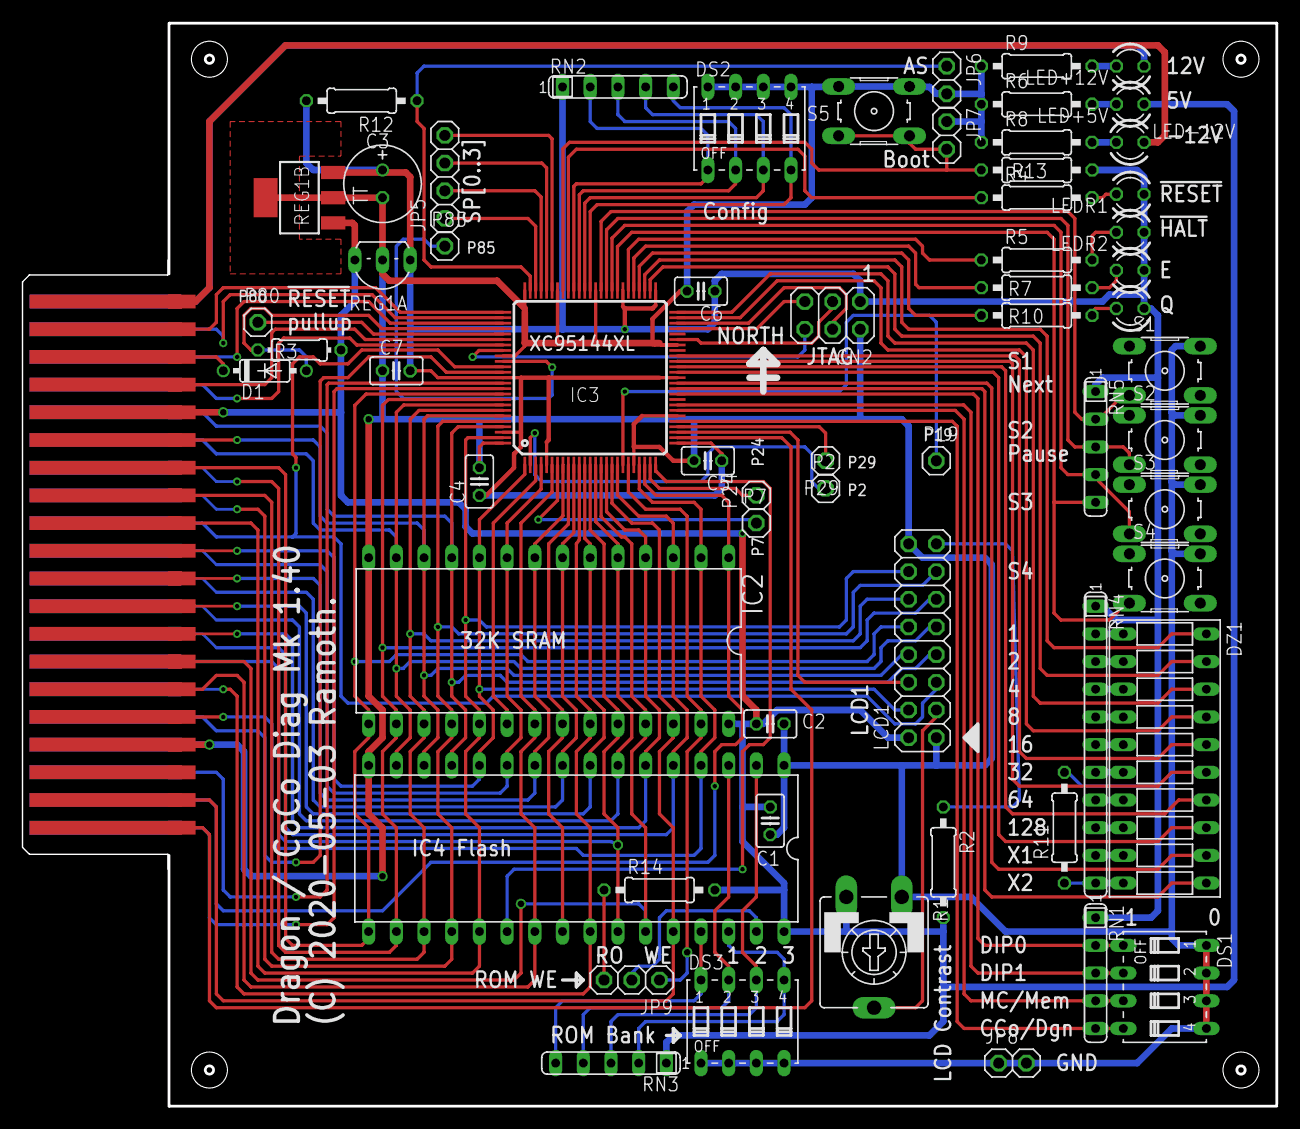
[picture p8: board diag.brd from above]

Board: 2 copper layers, 115.0 x 99.3 mm, 67 parts (0 on the bottom side), 113 nets.

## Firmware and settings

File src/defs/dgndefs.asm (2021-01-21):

*
* Deinitions for ports on Dragon 32/64/Alpha.
*
* 2004-11-16. P.Harvey-Smith.
* 	Fixed the stupid error I made in the defines below
*	that made all the non DPxxxxx defines equal to FF00 !!!
*
* 2004-10-10. P.Harvey-Smith.
*	Tidyed up a little, moved romdefs into their own file.
*

IO		equ		$ff00		; IO page on Dragon

*
* Most of these symbols will be defined twice, as some 
* of the Dragon code, sets DP=$FF, and uses direct page
* addressing to access the io ports, whilst some of it
* uses absolute addressing.
* The versions starting DP must be used with DP=$FF.
*

*Pia 0 and 1 standard on all Dragons.

DPPIA0DA	EQU		$00		; Side A Data/DDR
DPPIA0CRA	EQU		$01		; Side A Control.
DPPIA0DB	EQU		$02		; Side B Data/DDR
DPPIA0CRB	EQU		$03		; Side B Control.

PIA0DA		EQU		DPPIA0DA+IO	; Side A Data/DDR
PIA0CRA		EQU		DPPIA0CRA+IO	; Side A Control.
PIA0DB		EQU		DPPIA0DB+IO	; Side A Data/DDR
PIA0CRB		EQU		DPPIA0CRB+IO	; Side A Control.

DPPIA1DA	EQU		$20		; Side A Data/DDR
DPPIA1CRA	EQU		$21		; Side A Control.
DPPIA1DB	EQU		$22		; Side B Data/DDR
DPPIA1CRB	EQU		$23		; Side B Control.

PIA1DA		EQU		DPPIA1DA+IO	; Side A Data/DDR
PIA1CRA		EQU		DPPIA1CRA+IO	; Side A Control.
PIA1DB		EQU		DPPIA1DB+IO	; Side A Data/DDR
PIA1CRB		EQU		DPPIA1CRB+IO	; Side A Control.

* Dragon Alpha has a third PIA at FF24.

DPPIA2DA	EQU		$24		; Side A Data/DDR
DPPIA2CRA	EQU		$25		; Side A Control.
DPPIA2DB	EQU		$26		; Side B Data/DDR
DPPIA2CRB	EQU		$27		; Side B Control.

PIA2DA		EQU		DPPIA2DA+IO	; Side A Data/DDR
PIA2CRA		EQU		DPPIA2CRA+IO	; Side A Control.
PIA2DB		EQU		DPPIA2DB+IO	; Side A Data/DDR
PIA2CRB		EQU		DPPIA2CRB+IO	; Side A Control.

;WD2797 Floppy disk controler, used in Alpha Note registers in reverse order !
DPCmdRegA	EQU		$2F		; command/status			
DPTrkRegA	EQU		$2E		; Track register
DPSecRegA	EQU		$2D		; Sector register
DPDataRegA	EQU		$2C		; Data register

CmdRegA		EQU		DPCmdRegA+IO	; command/status			
TrkRegA		EQU		DPTrkRegA+IO	; Track register
SecRegA		EQU		DPSecRegA+IO	; Sector register
DataRegA	EQU		DPDataRegA+IO	; Data register

; Constants for Alpha AY-8912 sound chip, which is used to control
; Drive select and motor on the Alpha

AYIOREG		EQU		$0E		; AY-8912, IO Register number.
AYIdle		EQU		$00		; Make AY Idle.
AYWriteReg	EQU		$01		; Write AY Register
AYReadReg	EQU		$02		; Read AY Register
AYREGLatch	EQU		$03		; Latch register into AY

DSMask		EQU		$03		; Drive select mask.
MotorMask	EQU		$04		; Motor enable mask
DDENMask	EQU		$08		; DDEN Mask
ENPMask		EQU		$10		; Enable Precomp mask
NMIMask		EQU		$20		; NMI enable Mask

; Dragon 64/Alpha Serial port.
DPAciaData	EQU		$04		; Acia Rx/Tx Register
DPAciaStat	EQU		$05		; Acia status register
DPAciaCmd	EQU		$06		; Acia command register
DPAciaCtrl	EQU		$07		; Acia control register

AciaData	EQU		DPAciaData+IO	; Acia Rx/Tx Register
AciaStat	EQU		DPAciaStat+IO	; Acia status register
AciaCmd		EQU		DPAciaCmd+IO	; Acia command register
AciaCtrl	EQU		DPAciaCtrl+IO	; Acia control register

; constants for the ACIA status register

AciaSParityErr	EQU		$01		; parity error
AciaSFrameErr	EQU		$02		; framing error
AciaSOverrun	EQU		$04		; data overrun
AciaSRxFull	EQU		$08		; receiver register full
AciaSTxEmpty	EQU		$10		; transmit register empty
AciaSDCD	EQU		$20		; data carrier detect =0detect, 1=not detect
AciaSDSR	EQU		$40		; data set ready 0=ready, 1=not ready
AciaSIRQ	EQU		$80		; interrupt, 0=no int, 1=int

; constants for ACIA command register
AciaPMCMask	EQU		$C0		; mask for PMC bits
AciaTICMask	EQU		$0C		; transmitter interrupt control mask

AciaPMCPOdd	EQU		$00		; odd parity tx/rx
AciaPMCPEven	EQU		$40		; even parity tx/rx
AciaPMCPMark	EQU		$80		; mark parity tx, rx parity disabled
AciaPMCPSpace	EQU		$C0		; space parity tx, rx parity disabled
AciaPME		EQU		$20		; parity mode enable = 1, disable = 0
AciaREM		EQU		$10		; receiver echo mode, 0=no echo, 1=echo
AcidTICRHDis	EQU		$00		; RTS high, interrupt disabled
AcidTICRLEna	EQU		$04		; RTS low, interrupt enabled
AcidTICRLDis	EQU		$08		; RTS low, interrupt disabled
AcidTICRLBrk	EQU		$0C		; RTS low, interrupt disabled, break on txd
AciaIRD		EQU		$02		; receiver interrupt disable, 0=int enabled, 1=int disabled
AciaDTR		EQU		$01		; data terminal ready 0=DTR high, 1=DTR low

; constants for the ACIA control register 
; bits 0..3 specify the baud rate

AciaBrdMask	EQU		$0F		; baud rate mask
AciaCBrdExt	EQU		$00		; 1/16th external clock
AciaCBrd50	EQU		$01		; 50 baud
AciaCBrd75	EQU		$02		; 75 baud
AciaCBrd110	EQU		$03		; 110 baud
AciaCBrd135	EQU		$04		; 135 baud
AciaCBrd150	EQU		$05		; 150 baud
AciaCBrd300	EQU		$06		; 300 baud
AciaCBrd600	EQU		$07		; 600 baud
AciaCBrd1200	EQU		$08		; 1200 baud
AciaCBrd1800	EQU		$09		; 1800 baud
AciaCBrd2400	EQU		$0A		; 2400 baud
AciaCBrd3600	EQU		$0B		; 3600 baud
AciaCBrd4800	EQU		$0C		; 4800 baud
AciaCBrd7200	EQU		$0D		; 7200 baud
AciaCBrd9600	EQU		$0E		; 9600 baud
AciaCBrd19200	EQU		$0E		; 19200 baud

AciaCRxClk	EQU		$10		; receiver clock source, 0= external, 1=baud rate
AciaWrdMask	EQU		$60		; word length bits mask
AciaCWrd8	EQU		$00		; 8 bit word
AciaCWrd7	EQU		$20		; 7 bit word
AciaCWrd6	EQU		$40		; 6 bit word
AciaCWrd5	EQU		$60		; 5 bit word3
AciaCSBN	EQU		$80		; stop bit number, 0=1 bit, 1=2 bits

; Dragon Alpha Modem port (6850)

DPModemCtrl	EQU		$28		; Modem Control/Status
DPModemData	EQU		$29		; Modem Rx/Tx Data

ModemCtrl	EQU		DPModemCtrl+IO	; Modem Control/Status
ModemData	EQU		DPModemData+IO	; Modem Rx/Tx Data

;DragonDos Cartrage IO for WD2797

;WD2797 Floppy disk controler, used in DragonDos.
DPCmdRegD	EQU		$40		; command/status			
DPTrkRegD	EQU		$41		; Track register
DPSecRegD	EQU		$42		; Sector register
DPDataRegD	EQU		$43		; Data register

CmdRegD		EQU		DPCmdRegD+IO	; command/status	4		
TrkRegD		EQU		DPTrkRegD+IO	; Track register
SecRegD		EQU		DPSecRegD+IO	; Sector register
DataRegD	EQU		DPDataRegD+IO	; Data register

DPDSKCTLD	EQU		$48		; Disk DS/motor control reg
DSKCTLD		EQU		DPDSKCTLD+IO		

; Disk IO bitmasks (DragonDos).

NMIEnD    	EQU		%00100000 
WPCEnD    	EQU   		%00010000 
SDensEnD  	EQU   		%00001000 
MotorOnD  	EQU   		%00000100 
Drive0D		EQU		%00000000
Drive1D		EQU		%00000001
Drive2D		EQU		%00000010
Drive3D		EQU		%00000011
DriveMaskD	EQU		%00000011	; Mask to extract drives

; Disk IO bitmasks (Dragon Alpha).

;NMIEnA    	EQU		%10000000	; This is just a guess, but in current code just used as a flag 
Drive5or8	EQU		%10000000	; is drive in 5" or 8" mode Acording to circuit trace on R.Harding's machine
WPCEnA    	EQU	   	%01000000 	; Acording to circuit trace by R.Harding.
SDensEnA  	EQU   		%00100000 	; DDen Acording to circuit trace on R.Harding's machine
MotorOnA  	EQU   		%00010000 	
Drive0A		EQU		%00000001	; Drive selects acording to OS9 headers
Drive1A		EQU		%00000010
Drive2A		EQU		%00000100
Drive3A		EQU		%00001000
DriveMaskA	EQU		%00001111	; Mask to extract drives

; On the Alpha, NMI is enabled/disabled by setting CA2 of the third PIA, High=enabled.
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

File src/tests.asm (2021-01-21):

;
; Test routines for Diag cart.
;

;
; Quick RAM tests, just values $FF and $00
;

DoQuickTest	leau	QRamTest,pcr	; point to short test
		stu	TestVector	; set the test vector
GoTestRAM	leax	RamBanksSmall,pcr	; assume 4K
		tst	RAMFlag		; are we configured for 4K rams?
		beq	SetBanks	; yes use them
		
		leax	BankTableSize,x	; select large table

SetBanks	bsr	DoRamTest	; test first bank
		
		inc	LEDS

		ldb	RAMFlag		; Check RAM size
		cmpb	#DRAM64		; Check to see if we have 4K or 16K RAMS
		bhs	Rams64		; yes we do both banks as same chips
		
		ldb	#DIPOneBank	; just do one bank?
		lbsr	DIPMask		; test it
		bne	JustOne		; yes, skip second

Rams64		leax	4,x		; next table entry
		bsr	DoRamTest	; test second bank
JustOne		inc	LEDS
NoLongTests	rts


;
; Long RAM tests, test blocks, with all 255 values.
;
; on entry X points to a string to be displayed before beginning the tests.

DoLongTest	ldb	#DIPSkipLong	; skip long tests?
		lbsr	DIPMask		; check against DIPS
		bne	NoLongTests	; yes skip them

		tst	IsCoCo3		; Is this machine a CoCo3?
		bne	NoLongTests	; yes skip them, we will do specific test later

DoLong		leau	LRamTest,pcr	; point to long test
		stu	TestVector	; set the test vector
		
DoTests		lbsr	VCRLCDClrScr	; Clear LCD display, CR on VDG
		lbsr	DevWriteStr	; display it
		lbsr	WaitPause	; delay a little
		
		bra	GoTestRAM

;
; Do long or short test dependent on dip.
;
; on entry X points to a string to be displayed before beginning the tests.

DoLongOrShort	bsr	GetTestLength	; Set test length
		bra	DoTests		; go do it

;
; GetTestLength, returns the test type to perform in U.
; Checks the SkipLong DIP switch and if set returns a pointer to 
; the short test, otherwise a pointer to the long test.
;

GetTestLength	ldb	#DIPSkipLong	; skip long tests?
		lbsr	DIPMask		; check against DIPS
		bne	DoShortTest	; only do short test
		
		leau	LRamTest,pcr	; point to long test	
		bra	SetTestVec	

DoShortTest	leau	QRamTest,pcr	; point to short test	
SetTestVec	stu	TestVector	; set the test vector
		rts
		
;
; RAM tests, outputting to VDG and LCD.
;
; Entry :
; 	X 		= pointer to table of start, end address
;	TestVector	= address of test routine to run
; Exit
;	CC.Z	= set on error
;

DoRamTest	pshs	u,x

		tst	CoCo3Blocks	; Are we processing CoCo 3 RAM blocks?
		bne	ShowBlocks	; yes display for blocks
		
		pshs	x
		lbsr	LCDClrScr	; clear LCD screen.
		leax	LMessRamTest,pcr ; point to message
		lbsr	DevWriteStr
		
		puls	x
		
		ldd	,x		; print start address
		
		lbsr	DevHexWord		
		
		lbsr	DDash		; output dash, then dollar
		lbsr	DDollar		; 
		
		ldd	2,x		; print end address
		lbsr	DevHexWord
		bra	DoRamTest2	; do rest of test
	
ShowBlocks	pshs	x
		lbsr	LCDClrScr	; clear LCD screen.
		leax	LMessRamTestB,pcr ; point to message
		lbsr	DevWriteStr
	
		puls	x

		lda	CoCo3BlockNo	; get current block no
		anda	#BlockNoMask	; Mask out invalid bits
		lbsr	DevHexByte	; display it
		
DoRamTest2
		lbsr	DSpace		; print a space

		ldy	2,x		; get test addresses from table
		ldx	,x
		
		clr	TestContinue	; Flag beginning of RAM test
		
; not we cannot use indirect jsr [TestVector] as this gets assembled as the
; absolute 16 bit address of TestVector, we need the DP relative version.
		
RestartTest	ldu	TestVector	; run ram test	
		jsr	,u
		bne	RamTestFailed
		
		bsr	RAMPassed	; Display passed message
		bra	RamTestExit	; restore and exit	
		
RamTestFailed	bsr	RAMFail		; do ram fail output
		bne	RamTestExit	; next pressed, exit test
		clra	
		coma			; flag test to continue
		sta	TestContinue
		bra	RestartTest	; restart it....
		
RamTestExit	puls	u,x,pc		; restore and return

RAMPassed	leax	MessPassed,pcr	; Passed message
		lbsr	WriteStr
		
		leax	LPassed,pcr	; Passed message
		lbsr	LCDWriteStr
		
		lbra	WaitPause	; give user time to see it....

	
RAMFail		leax	MessFailedAt,pcr ; print failed message
		lbsr	WriteStr
		
		ldd	#$0001		; column 12 line 2
		lbsr	LCDGotoXY	; go to co-ordinates

		leax	LMessFailedAt,pcr	; point to fail message
		lbsr	LCDWriteStr	; write it to LCD
		
		ldd	TestFailAddr	; get address of first failure
		lbsr	DevHexWord	; display it
		
		lbsr	LSpace		; output a space
		
		leax	MessWrote,pcr	; Display byte written
		lbsr	WriteStr
		
		lda	#'w'		; wrote byte
		lbsr	LCDWriteChar	; write it
		
		lda	TestWrote	; get byte written
		lbsr	DevHexByte
		
		leax	MessRead,pcr	; Display byte read
		lbsr	WriteStr
		
		lbsr	LSpace		; output a space
		lda	#'r'		; wrote byte
		lbsr	LCDWriteChar	; write it

		lda	TestRead	; get byte read
		lbsr	DevHexByte
		
		lbsr	Newline		; print an EOL

RamFailWait	lbsr	QueryButton	; wait for button press

		cmpa	#ButtonNext	; Was next pressed?
		beq	FlagTerminate	; yes, flag terminate
		
		cmpa	#ButtonSkip	; Was it skip
		beq	RamFailExit	; yes flag skip...zero flag already set
		bra	RamFailWait	; neither wait for a valid button.....
		
FlagTerminate	andcc	#~FlagZero	; Flag, next so terminate
		
RamFailExit	rts

; If running in test mode im MAME, don't test the RAM we are using.....
		ifdef Test
FirstRam	equ	RAMTop+1
		else
FirstRam	equ	$0000
		endc	

; RAM banks if using 4K RAMS
RamBanksSmall	fdb	FirstRam,$1000
		fdb	$1000,$2000

; RAM banks if using 16K or 64K RAMS
RamBanksLarge	fdb	FirstRam,$4000
		fdb	$4000,$8000

BankTableSize	equ	(RamBanksLarge-RamBanksSmall)

;
; Quick RAM test
; 
; Entry:
;	A	= 0, start test from beginning <>0 restart test from last
;	X	= base of area to test
;	Y	= length of area to test
;
; Exit:
;	CC.C	= error
;	X	= error address
;
QRamTest	tst	TestContinue	; should we start from beginning ?
		beq	QRamTestStart	; yes, start from beginning
		
		tst	TestWrote	; what was the last value written?
		beq	QRamTestP1	; we where on pass with $00, continue it
		bra	QRamTestP0	; we where on pass with $FF, continue it
		
QRamTestStart	stx	TestBase	; save base of test
		sty	TestEnd		; save end of test
		
QRamTestP0	clra			; do a pass with $FF
		coma			
		bsr	QPass		; test it
		bne	QRamTestExit	; error, exit
		
QRamTestP1	clra			; do a pass with $00
		bsr	QPass		; test it

QRamTestExit	pshs	cc		; save codes
		puls	cc,pc		; restore and return
		
;
; QPass, do the actual testing of the RAM, called by QRamTest and
; LRamTest, returns with CC.Z set on sucesss, clear on failure.
;
; TestPage1, TestDPlus, TestDPlusBank should be setup before calling
; this routine will page in / out memory as needed.
;
; On failure the RAM vars TestRead, TestWrote and TestFailAddr are
; set, so that thgese can be displayed to the user.
;		
		
QPass		pshs	a		; save test value

		bsr	PageInRAM	; page RAM in

		tst	TestContinue	; are we continuing a test?
		beq	QPassStart	; no, start from beginning
		
		ldx	TestFailAddr	; get address to continue from
		ldb	TestSaved	; get saved value
		lda	TestWrote	; get test value
		bra	QPassContinue	; go continue test
		
QPassStart	ldx	TestBase	; get base of test
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

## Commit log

2021-01-21 Initial checkin of diagnostic board files.
    [diag.brd, diag.sch]
2021-01-21 Added 3D files for case. Added partscost. Updated readme.
    [DragonDiagBottom-v3.FCStd, DragonDiagBottom-v3.stl, DragonDiagTop-v2.FCStd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]

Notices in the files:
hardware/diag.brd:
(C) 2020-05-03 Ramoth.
